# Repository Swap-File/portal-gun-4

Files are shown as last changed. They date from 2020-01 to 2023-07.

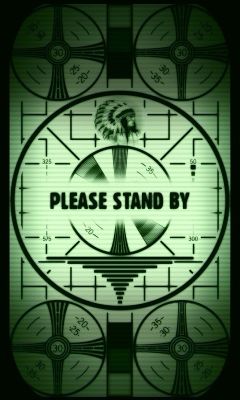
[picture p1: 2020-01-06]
internet/http/portalguns/test.jpg

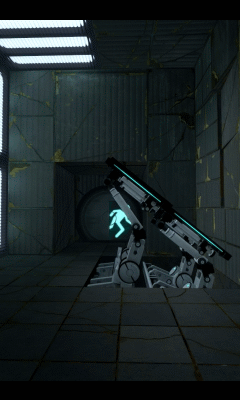
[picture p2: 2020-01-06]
intranet/assets/53.gif

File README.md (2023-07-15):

# portal-gun-4
Portal Gun IV

Gun:

[Raspberry Pi 4B](https://www.raspberrypi.org/) + [Laser Beam Pro C200](http://laserbeampro.com/) + [Pi NoIR Camera V2](https://www.raspberrypi.com/products/pi-noir-camera-v2/) + 3W IR Emitters

CAD Design inspired by [Kirby Downey](https://kirbydowney.com/)

5Ghz Bridge with hostapd via onboard WiFi + Fe-Pi Audio Z I2S Sound Card + USB CSR BT Dongle for tethering (avoids onboard WiFi/BT coexistence issues)

[Pololu MinIMU-9 v2](https://www.pololu.com/product/1268) + ADS1115 for Battery Meter and Temp Sensing

[4S 2200mAh LiPo](https://hobbyking.com/en_us/turnigy-2200mah-4s-20c-lipoly-pack-w-xt60-connector.html) + 3x [Pololu D36V28F5 5V 3.2A Regulators](https://www.pololu.com/product/3782) (Projector, CPU, Lighting and Sound)

APA102 LEDs + PAM8302 Class D Amplifier + ACS712 Current Sensor

KMS + EGL + GLES3 thanks to:

[kmscube](https://gitlab.freedesktop.org/mesa/kmscube/) + [OpenGL® ES 3.0 Programming Guide](https://github.com/danginsburg/opengles3-book) + [Modern OpenGL Tutorial Text Rendering 02](https://en.wikibooks.org/wiki/OpenGL_Programming/Modern_OpenGL_Tutorial_Text_Rendering_02)
 
Phone:

[QPython3](http://qpython.com/) + [Requests](http://docs.python-requests.org/en/latest/) + Bluetooth

Website:

[Apache](http://httpd.apache.org/) + [PHP](http://php.net/) + [mySQL](https://www.mysql.com/) on [Ubuntu](http://www.ubuntu.com/)

OS:
```
Raspberry Pi OS Lite
Release date: May 3rd 2023
System: 64-bit
Kernel version: 6.1
Debian version: 11 (bullseye)
Size: 308MB
Show SHA256 file integrity hash:
bf982e56b0374712d93e185780d121e3f5c3d5e33052a95f72f9aed468d58fa7
```
Packages:

```
gstreamer1.0-plugins-base gstreamer1.0-plugins-good gstreamer1.0-plugins-bad
libvisual-0.4-plugins gstreamer1.0-tools gstreamer1.0-plugins-ugly 
libgstreamer-plugins-base1.0-dev libgstreamer1.0-dev gstreamer1.0-alsa gstreamer1.0-libav
```
```
apache2 php libapache2-mod-php
```
```
dos2unix libdrm-dev libgles2-mesa-dev libgbm-dev ifstat python3-dbus libbluetooth-dev
hostapd libi2c-dev screen apt-file
```
Services:

```
systemctl unmask hostapd
systemctl enable hostapd
systemctl start hostapd
```
```
systemctl mask systemd-rfkill.socket systemd-rfkill.service
sudo apt purge libpam-chksshpwd
sudo apt remove libpam-chksshpwd
sudo apt purge rfkill
```
```
systemctl mask rpi-eeprom-update
systemctl disable apt-daily.service
systemctl disable apt-daily.timer
systemctl disable apt-daily-upgrade.timer
systemctl disable apt-daily-upgrade.service
sudo rpi-eeprom-update -a
```

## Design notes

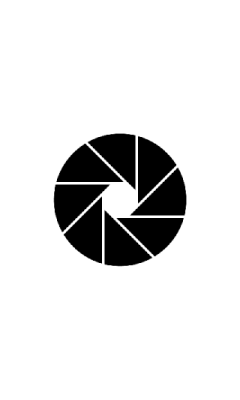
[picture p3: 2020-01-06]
intranet/assets/shutter.png

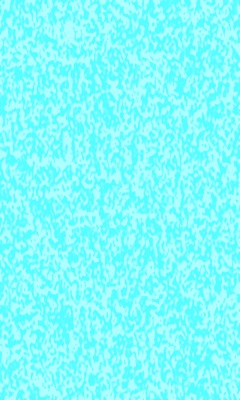
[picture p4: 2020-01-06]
intranet/assets/blue_0.jpg

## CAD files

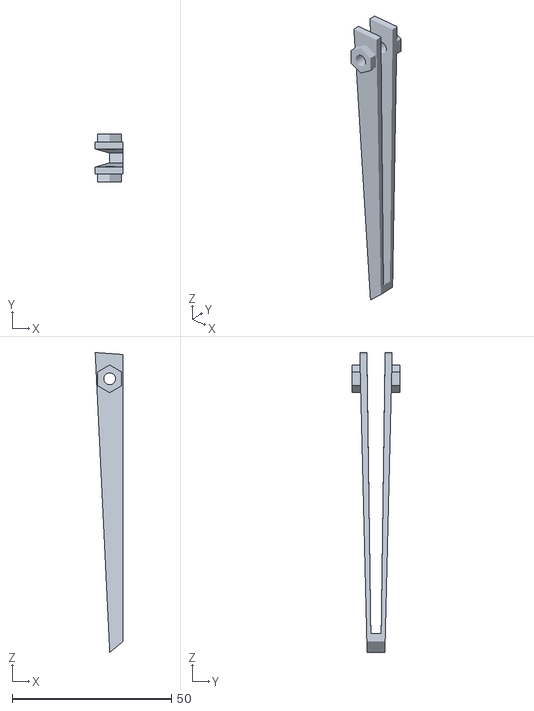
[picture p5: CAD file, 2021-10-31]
cad/finger/finger angle.stl
8.66 x 15.0 x 94.1

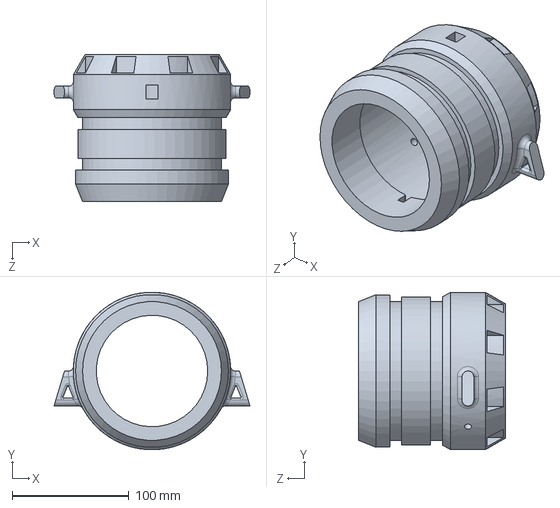
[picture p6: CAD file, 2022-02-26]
cad/front holes.SLDPRT
168.0 x 134.9 x 126.2 mm

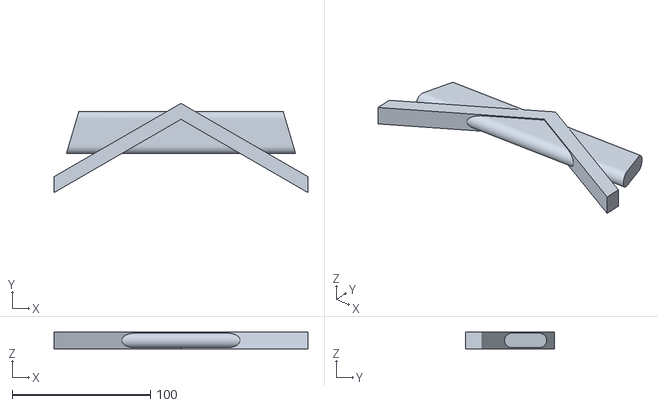
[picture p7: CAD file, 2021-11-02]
cad/trim/front trim holes only.stl
184.0 x 64.7 x 12.0

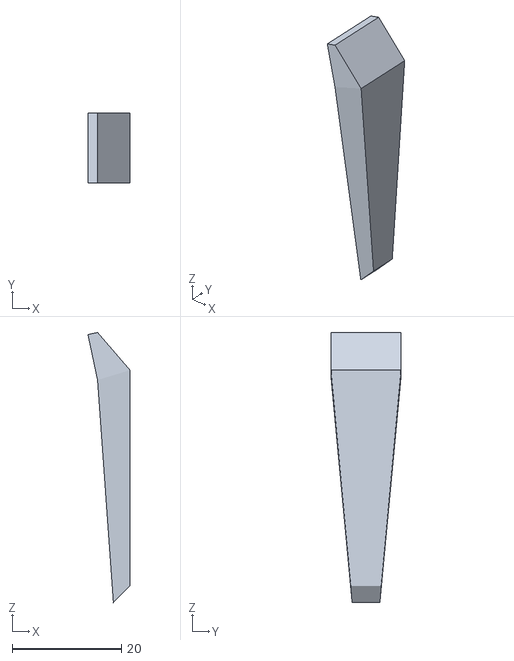
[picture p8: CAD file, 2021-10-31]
cad/finger/finger tip.stl
7.69 x 12.7 x 49.3

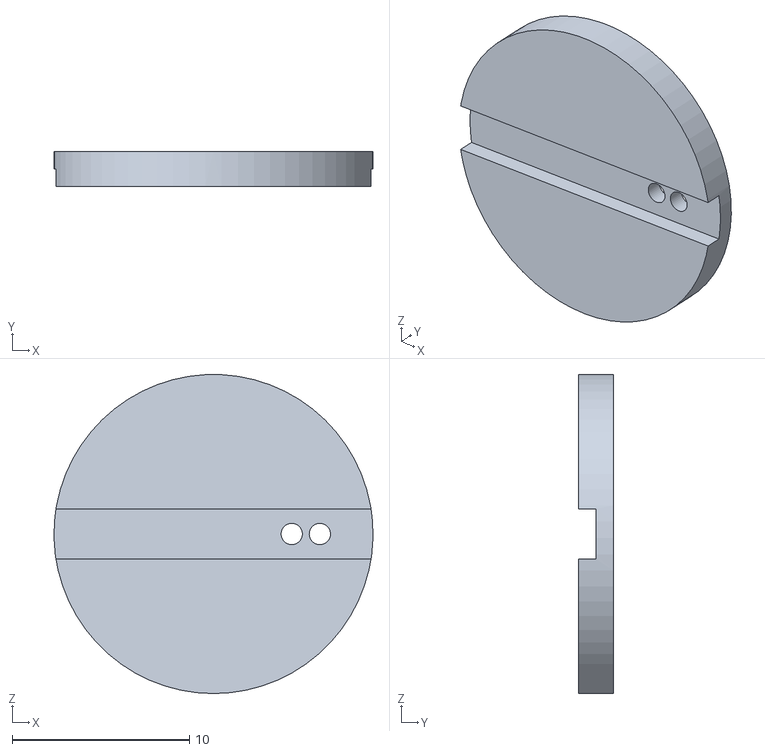
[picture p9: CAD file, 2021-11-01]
cad/projector shutter.STL
18.0 x 2.00 x 18.0

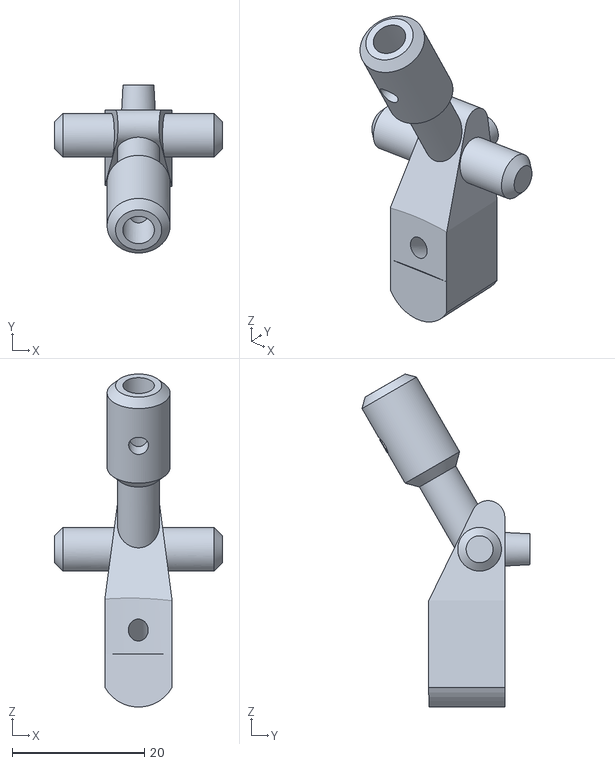
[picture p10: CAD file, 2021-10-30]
cad/finger/finger mount.STL
25.4 x 25.4 x 50.3

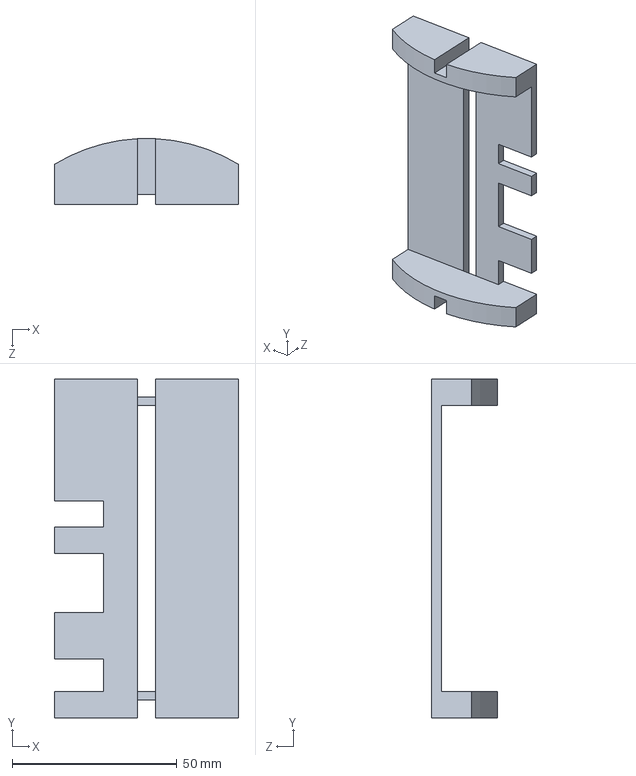
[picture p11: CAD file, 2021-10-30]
cad/sled lcd holder.SLDPRT
56.0 x 103.0 x 19.9 mm

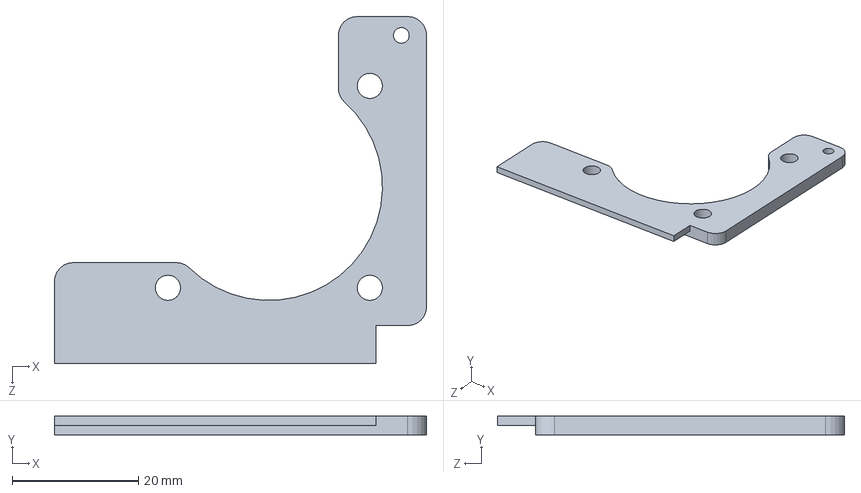
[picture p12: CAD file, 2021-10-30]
cad/fan bracket.SLDPRT
59.0 x 3.00 x 55.0 mm

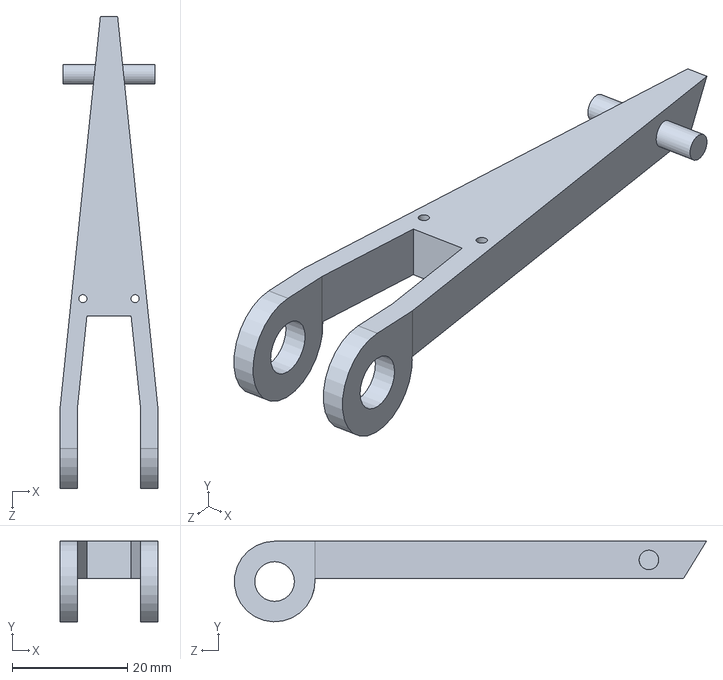
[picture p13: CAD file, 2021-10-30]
cad/finger/finger arm.SLDPRT
17.0 x 14.0 x 82.0 mm

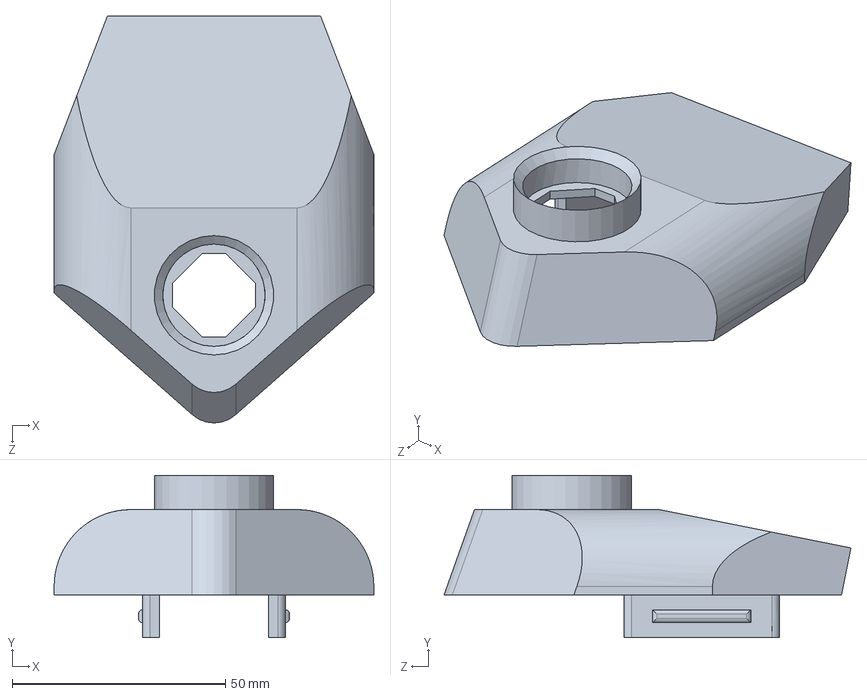
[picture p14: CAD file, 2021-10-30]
cad/Battery Lid.SLDPRT
75.0 x 38.0 x 95.5 mm

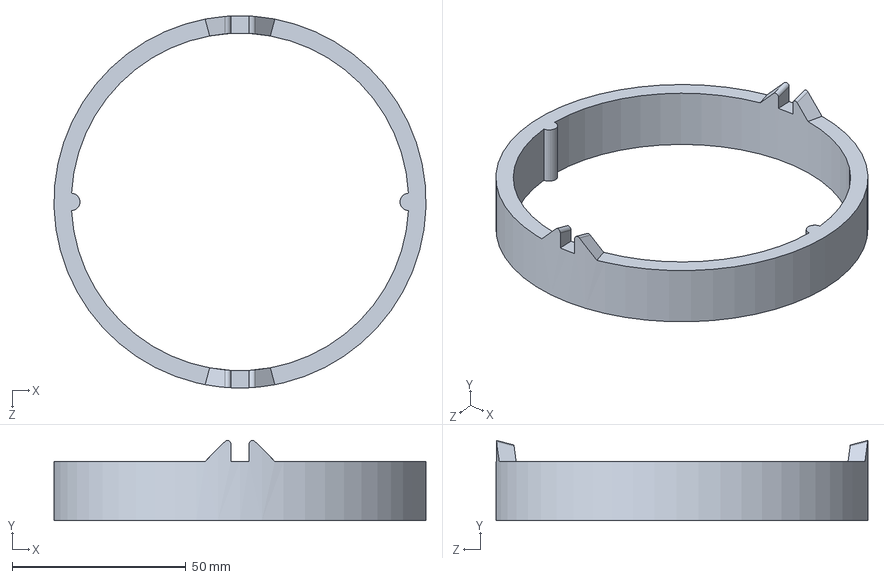
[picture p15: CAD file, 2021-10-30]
cad/led ring back.SLDPRT
107.0 x 23.0 x 106.9 mm

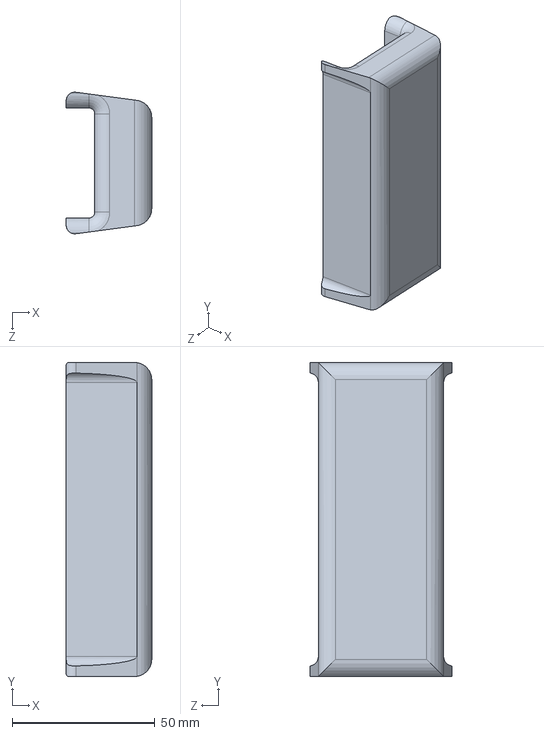
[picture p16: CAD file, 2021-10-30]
cad/big hand adapter.SLDPRT
30.0 x 110.0 x 49.6 mm

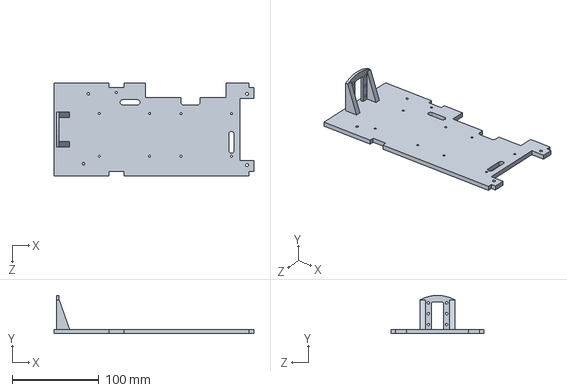
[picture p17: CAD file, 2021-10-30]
cad/sled.SLDPRT
230.0 x 44.1 x 107.5 mm

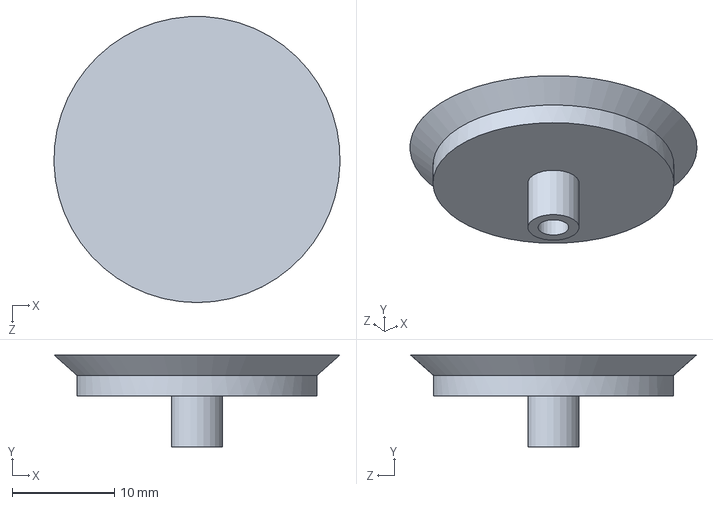
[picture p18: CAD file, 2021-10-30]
cad/led.SLDPRT
28.0 x 9.00 x 28.0 mm

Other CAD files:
cad/back.SLDPRT
cad/led ring front.SLDPRT
cad/finger gaurd.SLDPRT
cad/stand.SLDPRT
cad/3D.dwg
cad/Battery Lid.STL
cad/Sheets.dwg
cad/back.STL
cad/big hand adapter.STL
cad/fan bracket.STL
cad/finger gaurd.STL
cad/finger/finger arm.STL
cad/front holes.STL
cad/front.SLDPRT
cad/front.STL
cad/led ring back.STL
cad/led ring front.STL
cad/led.STL
cad/sled lcd holder.STL
cad/sled.STL
cad/stand.STL
cad/tool.SLDPRT
cad/tool.STL

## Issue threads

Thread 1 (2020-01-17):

projector power control

Swap-File, 2020-01-17:
delay start animations and sync with projector power

Swap-File, 2020-01-20:
update state diagram

Swap-File, 2020-03-15:
https://github.com/Swap-File/portal-gun-4/commit/aa162b3f9d81bb841b7df247740ffafaa37dea17

Closed 2020-03-15.

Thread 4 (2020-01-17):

fix points

Swap-File, 2020-01-17:
figure out why the points around the portal disappeared

Swap-File, 2020-01-20:
check this https://www.raspberrypi.org/forums/viewtopic.php?f=68&t=245646

Swap-File, 2020-02-06:
Switched to shaders

Closed 2020-02-06.

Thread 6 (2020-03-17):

fix intranet preview icons

Swap-File, 2020-03-17:

Swap-File, 2020-03-18:
Cleared out the live stuff that hasn't worked since V2.  Superseded by the dedicated physical aiming display on the device.
https://github.com/Swap-File/portal-gun-4/commit/fd465e689457e95f47c2515060cbd15374692820

Closed 2020-03-18.

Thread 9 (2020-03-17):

open shutter on state 0 when laser off?

Swap-File, 2020-03-17:

Swap-File, 2020-03-18:
https://github.com/Swap-File/portal-gun-4/commit/0edaa99c8b8bd9212dcef2553f66d64ddb35fb7e

may not use, its just fancy-ness

Swap-File, 2020-03-18:
Add this as an offshoot of shutter config, 0 is bypass, 1 is normal, 2 is fancy

Closed 2020-03-18.

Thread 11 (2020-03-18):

libvisual_corona

Swap-File, 2020-03-18:
look at the corona source code and figure out what its actually supposed to be doing with the input music

Swap-File, 2020-03-18:
void Corona::update(TimedLevel *pLevels)
{
	// Check for a beat
	int beatval = getBeatVal(pLevels);
	if (beatval > 1000)
	{
		int total = 0;
		for (int i = 0; i < 512; ++i)
			total += 2 * pLevels->frequency[0][i];
		double currval = 1.0 - exp(-total / 40000.0);
		m_oldval = (m_oldval + currval) / 2.0;

		double tx, ty;
		getAvgParticlePos(tx, ty);
		// If most of the particles are low down, use a launch
		if (ty < 0.2 && rand() % 4 != 0) {
			int p;
			double bv = m_oldval * 5.0;
			for (p = 0; p < nbParticules; ++p)
			{
				Particle *it = m_particles + p;
				if (it->y < 0.1) {
					double x = (it->x - tx) / bv;
					it->yvel += 0.01 * bv * exp(-1000.0 * x * x);
				}
			}
		}
		else
		{	// Otherwise use a swirl
			tx += random(-0.1, 0.1);
			ty += random(-0.1, 0.1);
			double bv = 0.009 * m_oldval;
			double bv2 = 0.0036 * m_oldval;
			if (rand() % 2 == 0) bv = -bv;
			m_movement.x = tx;
			m_movement.y = ty;
			m_movement.tightness = random(0.8 * bv, bv);
			m_movement.pull = random(1 - bv2, 1 - 0.2 * bv2);
			m_swirltime = 1;
		}

		pLevels->lastbeat = pLevels->timeStamp;
	}

	// Deal with the particles
	int p;
	for (p = 0; p < nbParticules; ++p)
	{
		Particle *it = m_particles + p;
		// Apply gravity
		it->yvel -= 0.0006;		// the gravity value

		// If there's an active swirl, swirl around it
		if (m_swirltime > 0) {
			double dx = it->x - m_movement.x;
			double dy = it->y - m_movement.y;
			double d = dx * dx + dy * dy;
			double ds = ::sqrt(d);
			double ang = atan2(dy, dx) + m_movement.tightness / (d + 0.01);
			it->xvel += (ds * m_movement.pull * cos(ang) - dx);
			it->yvel += (ds * m_movement.pull * sin(ang) - dy);
		}

		// Gitter
		it->xvel += random(-0.0002, 0.0002);
		it->yvel += random(-0.0002, 0.0002);

		// Clamp the velocity
		if (it->xvel < -0.1 ) it->xvel = -0.1;
		if (it->xvel > 0.1 ) it->xvel = 0.1;
		if (it->yvel < -0.1 ) it->yvel = -0.1;
		if (it->yvel > 0.1 ) it->yvel = 0.1;

		// Randomly move the particle once in a while
		if (rand() % (nbParticules / 5) == 0)
		{
			it->x = random(0, 1);
			it->y = random(0, 1);
			it->xvel = it->yvel = 0;
		}

		// Move and bounce the particle
		it->x += it->xvel;
		it->y += it->yvel;
		if (it->x < 0) { it->x = -it->x; it->xvel *= -0.25; it->yvel *= 0.25; }
		if (it->y < 0) { it->y = -it->y; it->xvel *= 0.25; it->yvel *= -0.25; }
		if (it->x > 1) { it->x = 2.0 - it->x; it->xvel *= -0.25; it->yvel *= 0.25; }
		if (it->y > 1) { it->y = 2.0 - it->y; it->xvel *= 0.25; it->yvel = 0; }
	}

	if (m_swirltime > 0) --m_swirltime;

	// Randomly change the delta field
	if (rand() % 200 == 0) chooseRandomSwirl();

	// Animate the waves
	m_waveloop += 0.6;

	// drawing.
	if (m_image != 0)
	{
		// Draw the particles on the bitmap
		drawParticules();

		// Apply the deltafield and update a few of its points
		applyDeltaField(m_nPreset == PRESET_BLAZE && m_width * m_height < 150000);

		int n = (m_width * m_height) / 100;
		for (int i = 0; i < n; ++i)
			setPointDelta(rand() % m_width, rand() % m_height);

		// If on the blaze preset, draw the particles again
		if (m_nPreset == PRESET_BLAZE)
			drawParticules();

		drawReflected();

		// Blur the bitmap
		blurImage();

		// If on the blaze preset, draw the particles one last time
		if (m_nPreset == PRESET_BLAZE)
			drawParticulesWithShift();
	}
}

Closed 2020-03-18.

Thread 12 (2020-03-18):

current meter

Swap-File, 2020-03-18:
do something useful with the current meter data that is being collected

Swap-File, 2020-04-21:
rearrange display.  add bt stats?

Swap-File, 2020-05-08:
https://github.com/Swap-File/portal-gun-4/commit/626576db60c85a3c7bc4a511efb7a6b8bfc2cf9d

Closed 2020-05-08.

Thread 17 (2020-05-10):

intranet control

Swap-File, 2020-05-10:
remove picture taking
remove camera streaming (mjpg removal)
combine camera and projector setting
review what 4 stats are shown in the corner

Closed 2020-05-10.

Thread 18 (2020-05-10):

default playlists

Swap-File, 2020-05-10:
set a good default solo and duo playlist
revisit standard saved playlists

Swap-File, 2020-05-19:
Solo playlist order will be different on Gordon and Chell to keep things exciting if both users are in solo mode within eyeshot.

Duo playlist will stay the same for consistency, and because generally in duo mode there is a lot of quick switching, then an effects demo on one gun.

Swap-File, 2020-05-20:
https://github.com/Swap-File/portal-gun-4/commit/4ff93dd91c9ad7c4bd30ed342ac6f2b7df053dd4

Closed 2020-05-20.

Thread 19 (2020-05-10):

calibrate party mode

Swap-File, 2020-05-10:
check volume levels for party modes

Swap-File, 2020-05-20:
Investigate if SGTL5000 DAP works, apply dap to incoming audio?
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

Swap-File, 2020-06-02:
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

This setting is not exposed in the driver.
https://github.com/torvalds/linux/blob/master/sound/soc/codecs/sgtl5000.c

So using the DAP for incoming audio will be non-trivial.  Test with fixed setting like before.

Swap-File, 2020-06-05:
Basic sgtl5000 driver to take over mux control:
https://github.com/Swap-File/portal-gun-4/commit/7dc68987c342c3e8444456e9736911a3bff56a97

breaks alsamixer, but meh, it works.

Swap-File, 2020-06-05:
Goal:
Likely using AVC, bass enhancement as LPF only, and potentially 5 band EQ.

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

Swap-File, 2020-06-07:
Check SYNAE, promote Goom.

Swap-File, 2020-06-08:
SYNAE init fixed, goom promoted, more calibration needed.

Swap-File, 2020-06-08:
Calibrate: Volume levels, potentially EQ balance the incoming signal

Swap-File, 2020-06-11:
https://github.com/Swap-File/portal-gun-4/commit/8dac6cc745b6f9d2c41d8cf5ebbc5b44331daddb

Closed 2020-06-11.

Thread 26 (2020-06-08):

check video assets

Swap-File, 2020-06-08:
some videos start with an audio glitch, check the source material, potentially reencode

Swap-File, 2020-06-09:
https://github.com/Swap-File/portal-gun-4/commit/a0cc7c408f124f0d3c21228ec15d06cfa1bde46a

Closed 2020-06-09.

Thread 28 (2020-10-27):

check spi

Swap-File, 2020-10-27:
spidev or bcm?

Swap-File, 2021-05-06:
bcm for now, needed for i2c anyway

Swap-File, 2021-08-07:
/dev/i2c and /dev/spi was tested, both should not be used, they are slow and the kernel prevents soundcard access.

Closed 2021-05-06.

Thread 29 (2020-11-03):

3d print enclosure?

Swap-File, 2020-11-03:

Swap-File, 2021-05-06:
Slated for version 4.1
3D Printed Case
Poly-carbonate Tube

Swap-File, 2022-01-27:
Keeping open until orange shoulder straps are sewn

Swap-File, 2022-02-26:
https://github.com/Swap-File/portal-gun-4/commit/b21b49ae80c27955f57669446c3839c97663f470

Closed 2022-03-03.

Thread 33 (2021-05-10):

state machine error

Swap-File, 2021-05-10:
On a swap from self to duo mode, we must spend one cycle in state 3 to allow the gstreamer engine time to switch while the portal is closed.

The state machine can now make two state transitions in one cycle hiding from gstreamer that we were ever inside of state 3

Swap-File, 2021-05-16:
https://github.com/Swap-File/portal-gun-4/commit/fec140e2ff6ac00d4982683c3446e936d2ff19d9

Closed 2021-05-16.

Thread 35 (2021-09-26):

paint over red leds

Swap-File, 2021-09-26:

Swap-File, 2021-10-01:
black sharpie

Closed 2021-10-01.

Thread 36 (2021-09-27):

handle led doesnt always animate

Swap-File, 2021-09-27:

Swap-File, 2021-10-01:
https://github.com/Swap-File/portal-gun-4/commit/49b9986c8119ec3a0ab07c4f6d1ba017873bc58d

Closed 2021-10-01.

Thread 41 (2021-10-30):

check imu data

Swap-File, 2021-10-30:

Swap-File, 2022-01-31:
https://github.com/Swap-File/portal-gun-4/commit/9bab527c6e233b79e642b619883a2afe74fdbfb5

Closed 2022-01-31.

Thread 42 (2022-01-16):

Update To bullseye

Swap-File, 2022-01-16:
Major camera changes

Check if KMS changes affect portal multi-monitor

measure new latency

Swap-File, 2022-01-16:
python-dbus is now dbus-python

Swap-File, 2022-01-17:
remove libgstaasink.so & libgstcacasink.so

Swap-File, 2022-01-21:
libcamera does not allow direct i2c access while the camera is in use, this breaks all the i2c functionality in all accessories, and affects timing.

libcamerasrc has minimal output support and is not ready for use.

libcamera-vid is acceptable, and UDP streaming works, but again it prevents direct i2c use.

Will self compile rpicamsrc and raspivid and check.

Good news is, I learned direct UDP streaming from any source (raspivid or libcamera-vid) likely the way to go for now.  It's faster than gstreamer's libcamsrc or rpicamsrc.

I can reflect the UDP packets for camera preview with the follow IP tables rule, lowering the primary video stream latency.
Example:
iptables -t mangle -A POSTROUTING -p udp --dport 9000 -j TEE --gateway 127.0.0.1

Swap-File, 2022-01-21:
https://forums.raspberrypi.com/viewtopic.php?t=323390

" Edit /boot/config.txt, remove the line "camera_auto_detect=1", and add "start_x=1" and "gpu_mem=128". Rebooting at this stage will reload the old V4L2 driver. Stop at this point if that is sufficient for your needs.

If you need raspistill/vid, then build the userland libraries for yourself.
Code: Select all

cd ~
sudo apt install cmake
mkdir bin
git clone https://github.com/raspberrypi/userland
cd userland
./buildme
cp build/bin/* ~/bin/
"

Swap-File, 2022-01-21:
Note: using Raspivid's preview window, it looks like a lower bound for video latency is ~115ms (camera to monitor)

Swap-File, 2022-01-21:
gst-launch-1.0 rpicamsrc ! image/mjpeg, width=640, height=480, framerate=30/1 ! queue ! udpsink port=9001 sync=false host=127.0.0.1
gst-launch-1.0 udpsrc port=9001 ! jpegdec ! queue ! kmssink sync=false
5% CPU  ~115ms

Swap-File, 2022-01-22:
64 bit OS benchmarks:

libcamera-vid -t 0 -o udp://127.0.0.1:9001 --width 640 --height 480 --codec MJPEG --framerate 30 --nopreview
gst-launch-1.0 udpsrc port=9001 ! jpegdec ! queue ! kmssink sync=false
50% CPU ~300ms of latency!

gst-launch-1.0 libcamerasrc ! video/x-raw, width=640, height=480, framerate=30/1 ! videoconvert ! jpegenc ! udpsink port=9001 sync=false host=127.0.0.1
gst-launch-1.0 udpsrc port=9001 ! jpegdec ! queue ! kmssink sync=false
45% CPU ~115ms

rpicamsrc does not work due to mmal support being incomplete on 64 bit Pi OS

Conclusion:  Bullseye + rpicamsrc

Will likely stay with BCM i2c for now, but I should investigate the latency cost to switch to linux native i2c.

Swap-File, 2022-01-22:
rtpvrawpay has slightly higher latency than jpegenc, and double the CPU, I guess packet handling overhead?

Swap-File, 2022-01-22:
gst-launch-1.0 rpicamsrc keyframe-interval=10 preview=0 ! video/x-h264,width=400,height=240,framerate=30/1,profile=baseline ! queue !  rtph264pay config-interval=1 pt=96 ! udpsink host=127.0.0.1 port=9000
gst-launch-1.0 udpsrc port=9000 caps=application/x-rtp,media=video,clock-rate=90000,encoding-name=H264 ! rtph264depay ! avdec_h264 ! queue ! kmssink sync=false
8% CPU 160ms latency

libcamera-vid -t 0 -o udp://127.0.0.1:9001 --width 640 --height 480 --codec h264--framerate 30 --nopreview
horrible latency, didn't even measure

raw video from rpicamsrc or libcamerasrc is the way to go.  will need to check if anything is better than jpegenc

Swap-File, 2022-01-22:
gst-launch-1.0 -vvv  rpicamsrc ! video/x-raw, width=640, height=480, framerate=30/1 ! kmssink sync=false
Lower limit of ~115ms

Swap-File, 2022-01-22:
fake kms is required for fixed resolution to work perfectly, no problems detect

Swap-File, 2022-01-26:
kms is a no go until hot plug is fixed.  power cycling projector while program is running can lead to a crash, is inconsistent.

Swap-File, 2022-02-01:
Invalid page flip at "drmDropMaster(drm.fd);" ? may need to move drmDropMaster(drm.fd); to the end of the function.

Or could be that drm_wait_master isn't waiting long enough at init, will test.

I've never seen the failure while running, only at init.

Swap-File, 2022-02-01:
I don't think I've triggered this since bullseye, it used to occasionally happen on cold boot.

`   drm = init_drm_legacy(device, mode_str, vrefresh,0);
    if (!drm ) {
        printf("failed to initialize DRM\n");
        system("sudo reboot");
        return -1;
    }`

Swap-File, 2022-02-02:
re-evaluate kms vs fkms on bullseye with drm double init fix

Closed 2023-07-16.

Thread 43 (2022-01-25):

fix playlist load

Swap-File, 2022-01-25:
fix playlist load when playlist is shorter than current.

Swap-File, 2022-01-27:
https://github.com/Swap-File/portal-gun-4/commit/51320e9fa7faed62cd76063ea01360fc0269d376

good enough, playlist management could be broken out into it's own file at some point

Closed 2022-01-27.

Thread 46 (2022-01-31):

Test website streaming

Swap-File, 2022-01-31:

Swap-File, 2022-02-08:
works

Swap-File, 2022-02-09:
Test gun power cycle while script is running (auto recovery behavior)

Swap-File, 2022-02-10:
works

Closed 2022-02-10.

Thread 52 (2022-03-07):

Solo Mode State Machine?

Swap-File, 2022-03-07:
Right now, solo mode takes a lot of presses to use.

Do we want to reduce the button presses?

3-1-1-1 could turn into 3-1-1 or 3-1

Swap-File, 2022-09-26:
nah, keeping it consistent for now

Closed 2022-09-26.

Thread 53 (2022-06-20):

intermittent first camera init fail

Swap-File, 2022-06-20:
Check if camera failure happens if Gordon projects and cell quick switches before Chell ever uses projector.

Swap-File, 2022-09-26:
https://github.com/Swap-File/portal-gun-4/issues/55 Maybe?

Closed 2022-09-26.

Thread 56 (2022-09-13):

rewind displays frames of video

Swap-File, 2022-09-13:

Closed 2022-09-26.

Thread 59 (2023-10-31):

pwm support on pi5?

Swap-File, 2023-10-31:
"6by9:

General advice would be to use the Linux standard APIs as they are then portable between all platforms. That would be libgpio for GPIO, and [sysfs](https://www.kernel.org/doc/html/latest/driver-api/pwm.html#using-pwms-with-the-sysfs-interface) for PWM (I'm amazed they haven't updated that one as sysfs is a pain)."

"Adafruit:

So clearly libgpiod is the winner at just over 3 times the speed of gpiozero!"

Swap-File, 2023-10-31:
https://github.com/raspberrypi/linux/blob/8dcc16f0adc50f5cb8a11a6dde238131d0ca45a0/drivers/pinctrl/pinctrl-rp1.c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

Swap-File, 2023-11-15:
https://forums.raspberrypi.com/viewtopic.php?t=359251

The SoC's onboard PWM block is probed first and has 2 channels - it gets called pwmchip0, and its created PWMs are called pwm0 and pwm1. The RP1 PWM controller has 4 channels, and when it probes there are already 2 PWMs in the system so it gets called pwmchip2 and creates global PWMs pwm2, pwm3, pwm4 and pwm5. But, the sysfs interface uses per-controller indexes to label its pwms, so exporting channel 2 of pwmchip2 creates .../pwmchip2/pwm2 (not pwm4).

(Maybe 2 external PWMs are still available? would still likely be on the wrong pins)

The GPIO sysfs interface and PWM sysfs interface are two different subsystems. The GPIO one is deprecated whilst the PWM one isn't.

```
#!/bin/bash
CHANNEL=2
CHIP=pwmchip2
PWM=pwm$CHANNEL

echo $CHANNEL > /sys/class/pwm/$CHIP/export
sleep 1
echo 240000 > /sys/class/pwm/$CHIP/$PWM/period
echo 120000 > /sys/class/pwm/$CHIP/$PWM/duty_cycle
echo 1 > /sys/class/pwm/$CHIP/$PWM/enable
```

Swap-File, 2024-03-05:
Wait for WiringPi to support Pi5 PWM prior to future testing.

https://github.com/WiringPi/WiringPi
https://github.com/GrazerComputerClub/WiringPi/issues/21

Swap-File, 2024-03-05:
Wait until WiringPi supports PWM for future investigation:

https://github.com/WiringPi/WiringPi

Swap-File, 2024-12-06:
Looks like WiringPi supports HW PWM on the Pi5.

https://github.com/WiringPi/WiringPi/pull/270

Test it on the Portal Guns.

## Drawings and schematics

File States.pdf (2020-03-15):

## Solo Mode State Transitions

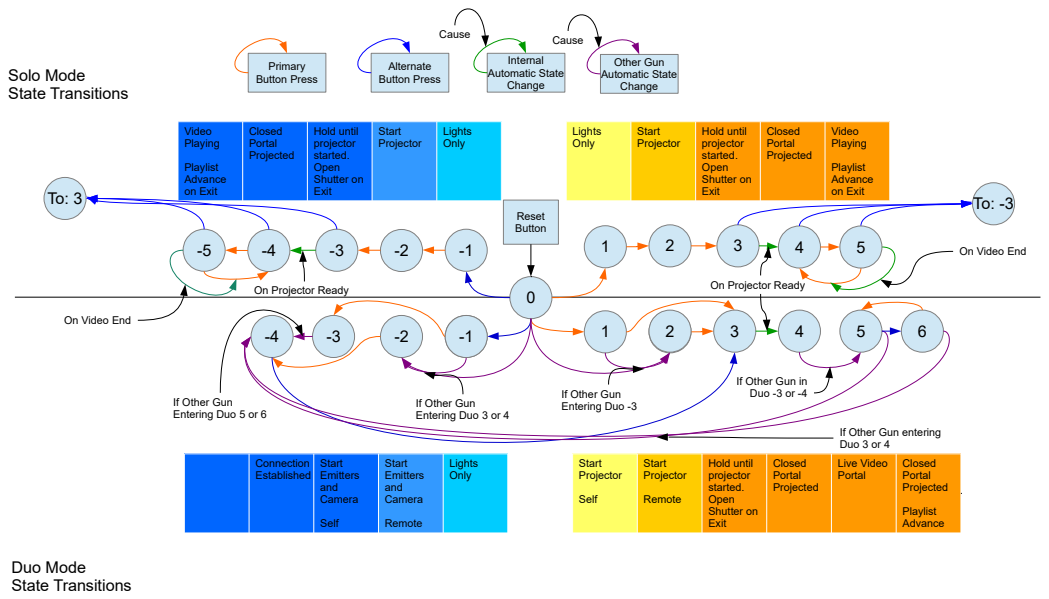
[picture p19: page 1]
Video Playing; Playlist Advance on Exit; Closed Portal Projected; Hold until projector started. Open Shutter on Exit; Start Projector; Lights Only; Connection Established; Start Emitters and Camera; Self; Remote; Playlist Advance; Primary Button Press; Alternate Button Press; Reset Button; Internal Automatic State Change; Cause; Duo Mode State Transitions; Other Gun Automatic State Change

On Video End

On Projector Ready

If Other Gun in
Duo -3 or -4

If Other Gun
Entering Duo -3

Entering Duo 5 or 6

Entering Duo 3 or 4

If Other Gun entering
Duo 3 or 4
Live Video
Portal

## Solo Mode Duo Force

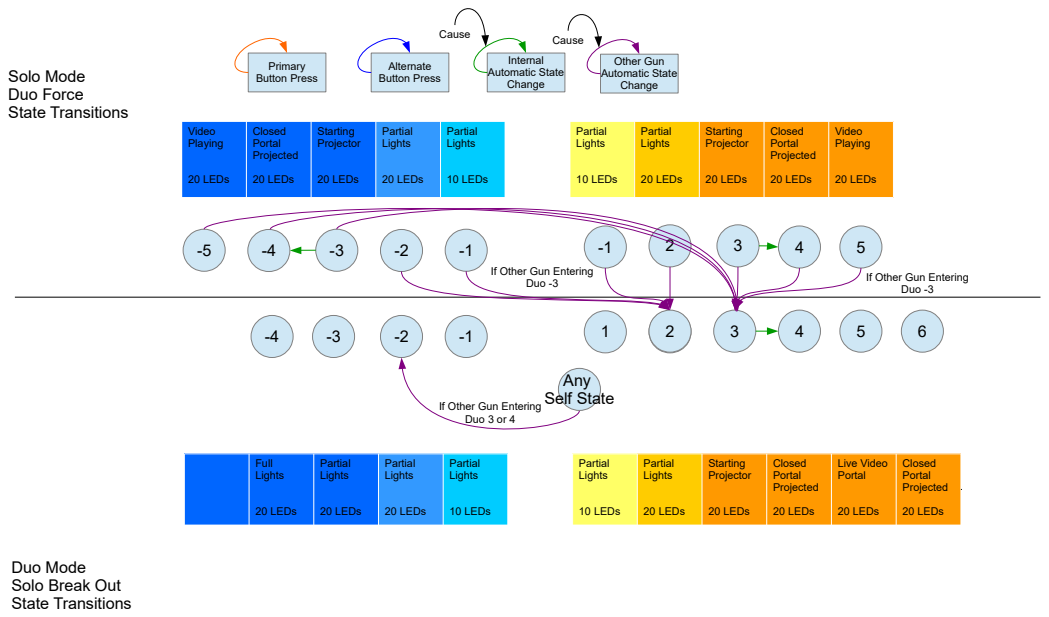
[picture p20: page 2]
Video Playing; 20 LEDs; Closed Portal Projected; Starting Projector; Partial Lights; 10 LEDs; Full Lights; Live Video Portal; State Transitions; Any; Duo 3 or 4; Duo -3; If Other Gun Entering; Primary Button Press; Alternate Button Press; Internal Automatic State Change; Cause; Other Gun Automatic State Change

If Other Gun Entering

Self State If Other Gun Entering

Duo Mode
Solo Break Out
State Transitions

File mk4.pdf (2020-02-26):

# Cellphone Bridge

# Website

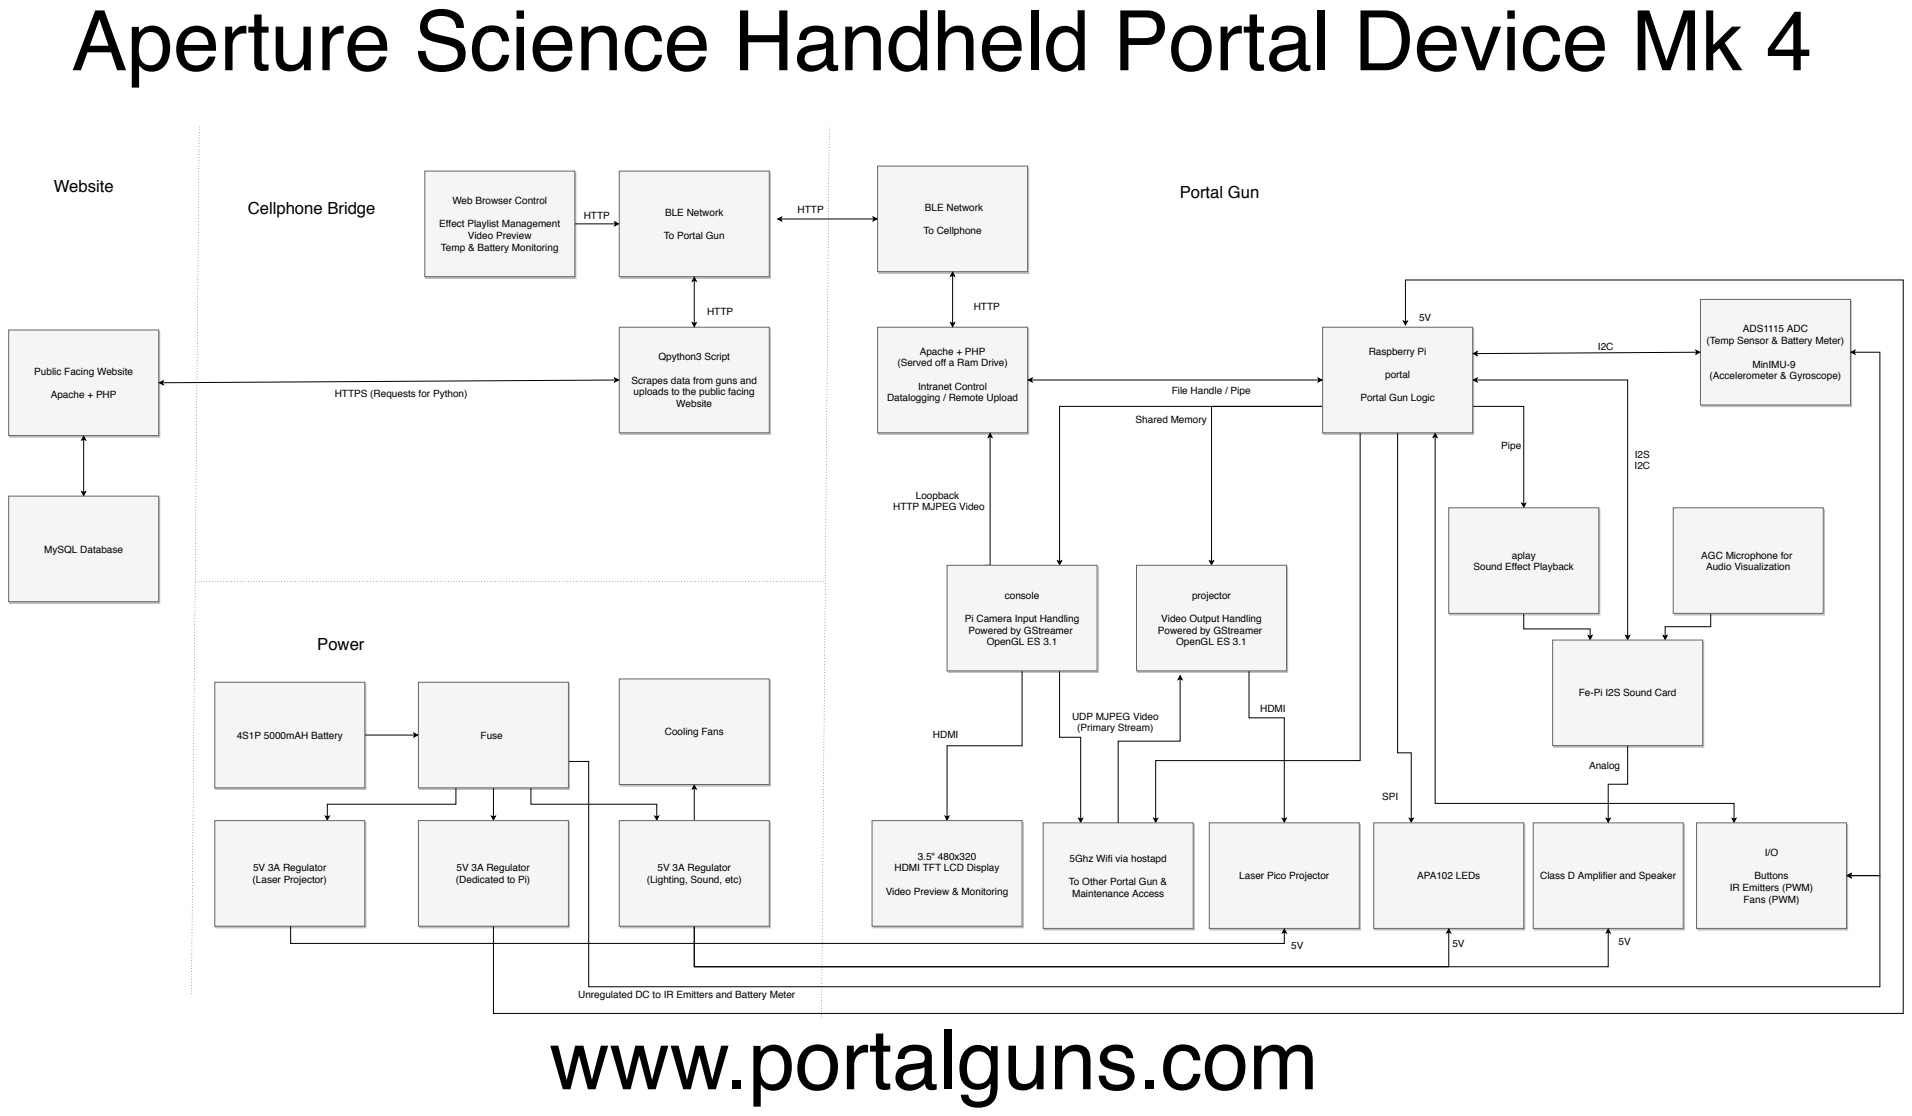
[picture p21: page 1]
BLE Network; Qpython3 Script; Website; Apache + PHP; HTTP; To Cellphone; Intranet Control; Pipe; Shared Memory; SPI; Raspberry Pi; portal; ADS1115 ADC; MinIMU-9 (Accelerometer & Gyroscope); aplay; HDMI; projector; Laser Pico Projector; APA102 LEDs; Class D Amplifier and Speaker; Portal Gun; 4S1P 5000mAH Battery; Fuse; Cooling Fans; Power; MySQL Database; 5V 3A Regulator (Laser Projector); console; Analog

Aperture Science Handheld Portal Device Mk 4

Web Browser Control

Effect Playlist Management
Video Preview
Temp & Battery Monitoring

To Portal Gun

(Temp Sensor & Battery Meter)

Apache + PHP
(Served off a Ram Drive)

Public Facing Website

Scrapes data from guns and
uploads to the public facing

HTTPS (Requests for Python)

Datalogging / Remote Upload

File Handle / Pipe

Portal Gun Logic

Loopback
HTTP MJPEG Video

AGC Microphone for
Audio Visualization

Sound Effect Playback

Pi Camera Input Handling
Powered by GStreamer
OpenGL ES 3.1

Video Output Handling

Fe-Pi I2S Sound Card

UDP MJPEG Video
(Primary Stream)

HDMI TFT LCD Display

5Ghz Wifi via hostapd

5V 3A Regulator
(Dedicated to Pi)

(Lighting, Sound, etc)
www.portalguns.com

Buttons
IR Emitters (PWM)
Fans (PWM)

To Other Portal Gun &
Maintenance Access

Video Preview & Monitoring

Unregulated DC to IR Emitters and Battery Meter

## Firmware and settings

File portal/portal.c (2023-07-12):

#include "common/memory.h"
#include "i2c.h"
#include "io.h"
#include "led.h"
#include "udp.h"
#include "pipe.h"
#include "state.h"
#include <stdio.h>
#include <stdlib.h> //exit
#include <signal.h> //SIGPIPE
#include <unistd.h> //getuid
#include <bcm2835.h>

void INThandler(int dummy) {
    printf("\nCleaning up...\n");
	pipe_cleanup();
	printf("LED wipe...\n");
    led_wipe();
    shared_cleanup();
    exit(1);
}

int main(void)
{
    if (getuid()) {
        printf("Run as root!\n");
        exit(1);
    }

    /* cleanup incase of straggling processes */
    pipe_cleanup();

    struct gun_struct *this_gun;
    shared_init(&this_gun,true);

    /* catch ctrl+c for exit */
    signal(SIGINT, INThandler);
    signal(SIGTERM, INThandler);
    signal(SIGKILL, INThandler);

    /* setup libraries */
	udp_init(this_gun->gordon);
	pipe_init(this_gun);
    bcm2835_init();
    led_init(this_gun->gordon);
    io_init();
    i2c_init();
 
    /* toggles every other cycle, cuts 100hz core tick speed to 50hz */
    bool freq_50hz = true;

    /* reset timer to now to avoid missing first cycle */
    uint32_t time_start = millis();

    while (1) {
        bool frameskip = false;
        /* Cycle Delay */
        time_start += 10;
        uint32_t predicted_delay = time_start - millis();
        if (predicted_delay > 10) predicted_delay = 0; //check for overflow
        if (predicted_delay != 0) {
            /* Update servos at 20ms intervals assuming we have enough delay, otherwise skip it */
            if (predicted_delay >= 2 && freq_50hz) {
                predicted_delay -= io_servo(this_gun->servo_open);
            }
            delay(predicted_delay);
        } else {
            time_start = millis(); //reset timer to now to skip idle
            frameskip = true;
        }

        /* Cycle Setup */
        this_gun->clock = millis(); //stop time for duration of frame
        freq_50hz = !freq_50hz;

        this_gun->state_duo_previous = this_gun->state_duo;
        this_gun->state_solo_previous = this_gun->state_solo;
        this_gun->other_gun_state_previous = this_gun->other_gun_state;

        /* Program Code */
        pipe_update(this_gun);

        /* Read Physical Buttons */
        int button_event = io_update(this_gun);
        if (button_event == BUTTON_LONG_RESET) system("reboot");
		
		/* Handle remote buttons  */
		pipe_button_out(button_event,this_gun->gordon);

        /* Otherwise Read Web Buttons */
        if (button_event == BUTTON_NONE) button_event = pipe_www_in(this_gun);
        //read other gun's data, only if no button events are happening this cycle

        /* Otherwise Read Other Gun */
        while (button_event == BUTTON_NONE) {
            int result = udp_receive_state(&(this_gun->other_gun_state),&(this_gun->other_gun_clock),&(this_gun->other_gun_health));
            if (result <= 0) break;  //read until buffer empty
            else this_gun->other_gun_last_seen = this_gun->clock;  //update time data was seen
            if (millis() - this_gun->clock > 5) break; //flood protect
        }

        /* Process State changes */
        state_engine(button_event,this_gun);

        /* Alternate blocking tasks to keep core at 100hz */
        if(freq_50hz)
            this_gun->brightness = led_update(this_gun);
        else
            i2c_update(this_gun);

        /* Send data to other gun and www output */
        static uint32_t time_udp_send = 0;
        if (this_gun->clock - time_udp_send > 100) {
            udp_send_state(this_gun->state_duo,this_gun->clock,this_gun->gun_health);
            time_udp_send = this_gun->clock;
            pipe_www_out(this_gun);
        }

        /* FPS counter */
        fps_counter("Portal:    ",this_gun->clock * 1000,frameskip);
    }
    return 0;
}

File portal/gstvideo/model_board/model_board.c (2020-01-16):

#include <stdio.h>
#include <stdlib.h>
#include <math.h>  //sqrt
#include <stdbool.h>
#include <gst/gst.h>
#include <gst/gl/gl.h>
#include <GL/glx.h>
#include <GL/glxext.h>
#include "png_texture.h"
#include "../gstvideo.h"

int last_acceleration[2] = {0,0};

//textures
GLuint orange_1,blue_n,orange_n,orange_0,blue_0,blue_1,texture_orange,texture_blue,circle64;

//vertex lists
GLuint video_quad_vertex_list,event_horizon_vertex_list,event_horizon2_vertex_list,portal_vertex_list,shutter_vertex_list;

float portal_spin = 0;
float event_horizon_spin = 0;

float event_horizon_vertex_list_shimmer = 0;
bool event_horizon_vertex_list_shimmer_direction = true;

float event_horizon_transparency_level = 0;

float global_zoom = 0;

float torus_offset[360];
float running_magnitude;
float angle_target;
float angle_target_delayed;

//texture scrolling
GLfloat donut_texture_scrolling = 0.0;

/* Borrowed from glut, adapted */
void draw_torus_vbo(){

	#define r 1.4
	#define R 9.8
	#define nsides 30
	#define rings 60
	
	int texcount=0,vertcount=0;
	
	GLfloat points[(nsides + 1) * rings * 2 *6];
	GLfloat tex[(nsides + 1) * rings * 2 * 4];

	GLfloat ringDelta = 2.0 * M_PI / rings;  //x and y 
	GLfloat sideDelta = 2.0 * M_PI / nsides; //z

	GLfloat theta = 0.0;
	GLfloat cosTheta = 1.0;
	GLfloat sinTheta = 0.0;
	
	for (int i = rings - 1; i >= 0; i--) {
		GLfloat theta1 = theta + ringDelta; //from 0 to 6.28
		
		GLfloat cosTheta1 = cos(theta1);
		GLfloat sinTheta1 = sin(theta1);

		GLfloat phi = 0.0;
		
		int index_deg = (360 - portal_spin + ( theta1 * 360  / (2*M_PI)));
		
		while (index_deg >= 360) index_deg -=360;
		
		GLfloat r_using = r + torus_offset[index_deg];
		GLfloat R_using = R - torus_offset[index_deg];
		
		for (int j = nsides; j >= 0; j--) {

			phi += sideDelta;
			
			GLfloat cosPhi = cos(phi);
			GLfloat sinPhi = sin(phi);
			
			GLfloat dist = R_using + r_using * cosPhi;
			
			GLfloat s0 = 20.0 * theta / (2.0 * M_PI);
			GLfloat s1 = 20.0 * theta1 / (2.0 * M_PI);
			GLfloat t = 2.0 * phi / (2.0 * M_PI);  //this seems to control texture wrap around the nut

			//glNormal3f(cosTheta1 * cosPhi, -sinTheta1 * cosPhi, sinPhi);
			tex[texcount++] = s0;
			tex[texcount++] = t - donut_texture_scrolling;
			points[vertcount++] =cosTheta1 * dist;
			points[vertcount++] =-sinTheta1 * dist;
			points[vertcount++] =r_using * sinPhi;
		
			//glNormal3f(cosTheta * cosPhi, -sinTheta * cosPhi, sinPhi);
			tex[texcount++] = s1;
			tex[texcount++] = t - donut_texture_scrolling;
			points[vertcount++] =cosTheta * dist;
			points[vertcount++] =-sinTheta * dist;
			points[vertcount++] =r_using * sinPhi;
		}
		
		theta = theta1;
		cosTheta = cosTheta1;
		sinTheta = sinTheta1;
	}
	
	glTexCoordPointer(2, GL_FLOAT, 0, tex);
	glVertexPointer(3, GL_FLOAT, 0, points);
	glDrawArrays(GL_TRIANGLE_STRIP, 0, (nsides + 1) * rings * 2);	//3720 vectors
}

//trail of points
#define TRAIL_QTY    6
#define TRAIL_LENGTH 20
#define TRAIL_OD     9.2
#define TRAIL_ID     2
static float cardinal_offset = 0.0;
static float helical_offset = 0.0;
static GLfloat point_vertexes[TRAIL_QTY * 3 * TRAIL_LENGTH];
static GLfloat point_colors[TRAIL_QTY * 4 * TRAIL_LENGTH];
static int head_offset = 0;

void draw_point_sprite_vertexes(void){
	
	//first decay ALL trail points, alpha is stored in 4th positions of color array
	for (int i = 3; i < TRAIL_QTY * 4 * TRAIL_LENGTH; i += 4) point_colors[i] *= 0.9;
	
	//overwrite the oldest point in each tail with the new head, render order doesnt matter
	head_offset = (head_offset + 1) % TRAIL_LENGTH; 
	float helical_index = 0;
	//do each head once
	for (int trail_head = 0; trail_head < TRAIL_QTY; trail_head++){
		
		//find the start of each trail, add the offset to get to the new head
		int vertex_index = trail_head * 3 * TRAIL_LENGTH + head_offset * 3;
		int color_index  = trail_head * 4 * TRAIL_LENGTH + head_offset * 4;	
		
		//find how far around the circle this head is
		float cardinal_index = (float)trail_head * (( 2 * M_PI )/((float)3));  //evenly space all heads
		
		//offset the position to get movement in a circle (controls cardinal speed)
		float cardinal_position = cardinal_index + cardinal_offset; 
			
		//how far to spin the helix
		helical_index =	helical_index + (( 2 * M_PI )*60.0/360.0);
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

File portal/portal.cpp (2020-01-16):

#include "portal.h"
#include "sharedmem.h"
#include "i2cread.h"
#include "ledcontrol.h"
#include "udpcontrol.h"
#include "pipecontrol.h"
#include "statemachine.h"
#include <stdio.h>
#include <stdint.h>
#include <stdlib.h>
#include <string.h>
#include <signal.h>
#include <unistd.h>
#include <sys/types.h>
#include <time.h>
#include <bcm2835.h>

void INThandler(int dummy) {
	printf("\nCleaning up...\n");
	ledcontrol_wipe();
	pipecontrol_cleanup();
	exit(1);
}

int main(void){
	
	if (getuid()) {
		printf("Run as root!\n");
		exit(1);
	}

	pipecontrol_cleanup();
	
	struct this_gun_struct *this_gun;
	shm_setup(&this_gun,true );
	
	//catch broken pipes to respawn threads if they crash
	signal(SIGPIPE, SIG_IGN);
	//catch ctrl+c when exiting
	signal(SIGINT, INThandler);
	
	//stats
	uint32_t time_start = 0;
	int missed = 0;
	uint32_t time_fps = 0;
	int fps = 0;
	uint32_t time_delay = 0;
	int changes = 0;
	
	//setup libaries
	web_output(*this_gun);
	bcm2835_init();
	ledcontrol_setup();
	i2creader_setup();	
	udpcontrol_setup();
	pipecontrol_setup();
	
	bool freq_50hz = true; //toggles every other cycle, cuts 100hz to 50hz

	while(1){
		//cycle start code - delay code
		time_start += 10;
		uint32_t predicted_delay = time_start - millis(); //calc predicted delay
		if (predicted_delay > 10) predicted_delay = 0; //check for overflow
		if (predicted_delay != 0){
			delay(predicted_delay); 
			time_delay += predicted_delay;
		}else{
			time_start = millis(); //reset timer to now
			printf("MAIN Skipping Idle...\n");
			missed++;
		}
		this_gun->clock = millis();  //stop time for duration of frame
		freq_50hz = !freq_50hz; 
		this_gun->state_duo_previous = this_gun->state_duo;
		this_gun->state_solo_previous = this_gun->state_solo;
		this_gun->other_gun_state_previous = this_gun->other_gun_state;
		
		//program code starts here
		update_temp(&(this_gun->coretemp));
		update_ping(&(this_gun->latency));
		update_ifstat(&(this_gun->kbytes_wlan),IFSTAT_WLAN);
		update_ifstat(&(this_gun->kbytes_bnep),IFSTAT_BNEP);
		update_iw(&(this_gun->dbm), &(this_gun->tx_bitrate));
		
		//read states from buttons
		int button_event = BUTTON_NONE;	
		button_event = io_update(*this_gun);

		//if no event, read from the web
		if (button_event == BUTTON_NONE) button_event = read_web_pipe(*this_gun);
		//read other gun's data, only if no button events are happening this cycle

		//if still no event, read button from the other gun for processing
		while (button_event == BUTTON_NONE){
			int result = udp_receive_state(&(this_gun->other_gun_state),&(this_gun->other_gun_clock));
			if (result <= 0) break;  //read until buffer empty
			else this_gun->other_gun_last_seen = this_gun->clock;  //update time data was seen
			if (millis() - this_gun->clock > 5) break; //flood protect
		}

		if (this_gun->video_done){
			if (this_gun->state_solo == 4) this_gun->state_solo = 3;
			else if (this_gun->state_solo == -4) this_gun->state_solo = -3;
			this_gun->video_done = false;
		}
						
		//process state changes
		local_state_engine(button_event,*this_gun);
		if (button_event != BUTTON_NONE) changes++;
		
		//OUTPUT TO gstvideo (combo video and 3d data)
		//gstvideo_command(*this_gun, other_gun.clock);

		//switch off updating the leds or i2c every other cycle, each takes about 1ms
		if(freq_50hz){ 
			this_gun->brightness = led_update(*this_gun);
		}
		else{
			i2creader_update(*this_gun);
		}
		
		audio_effects(*this_gun);
	
		//send data to other gun
		static uint32_t time_udp_send = 0;
		if (this_gun->clock - time_udp_send > 100){
			udp_send_state(this_gun->state_duo,this_gun->clock);
			time_udp_send = this_gun->clock;
			web_output(*this_gun);
		}
		
		//cycle end code - fps counter and stats
		fps++;
		if (time_fps < millis()){		
			printf("MAIN FPS:%d mis:%d idle:%d%% changes:%d \n",fps,missed,time_delay/10,changes);
			fps = 0;
			time_delay = 0;
			time_fps += 1000;
			//readjust counter if we missed a cycle
			if (time_fps < millis()) time_fps = millis() + 1000;
		}	
	}
	return 0;
}

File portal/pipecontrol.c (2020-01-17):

#include "pipecontrol.h"
#include "portal.h"
#include <sys/resource.h> //setpriority
#include <unistd.h> //sleep
#include <fcntl.h>  
#include <stdio.h>
#include <stdlib.h> //system exit getenv
#include <string.h> //strstr
#include <sys/stat.h> //mkfifo  
#include <bcm2835.h>

int temp_in;
int web_in;

FILE *iw_fp;
FILE *ifstat_wlan0_fp;
FILE *ifstat_bnep0_fp;
FILE *bash_fp;
FILE *ping_fp;

void pipecontrol_cleanup(void){
	printf("KILLING OLD PROCESSES\n");
	system("pkill gst*");
	system("pkill mjpeg*");
}

void pipecontrol_setup(bool gordon){
	
	//let this priority get inherited to the children
	setpriority(PRIO_PROCESS, getpid(), -10);

	system("sudo -E xinit ~/portal/gstvideo/auto.sh &");
	sleep(5);
	
	system("LD_LIBRARY_PATH=/usr/local/lib mjpg_streamer -i 'input_file.so -f /var/www/html/tmp -n snapshot.jpg' -o 'output_http.so -w /usr/local/www' &");
	
	//kick the core logic up to realtime for faster bit banging
	piHiPri(40);
	
	bash_fp = popen("bash", "w");
	fcntl(fileno(bash_fp), F_SETFL, fcntl(fileno(bash_fp), F_GETFL, 0) | O_NONBLOCK);

	mkfifo ("/home/pi/FIFO_PIPE", 0777 );
	
	if ((web_in = open ("/home/pi/FIFO_PIPE",  ( O_RDONLY | O_NONBLOCK))) < 0) {
		perror("WEB_IN: Could not open named pipe for reading.");
		exit(-1);
	}
	
	fprintf(bash_fp, "sudo chown www-data /home/pi/FIFO_PIPE\n");
	fflush(bash_fp);
	
	if ((temp_in = open ("/sys/class/thermal/thermal_zone0/temp",  ( O_RDONLY | O_NONBLOCK))) < 0) {
		perror("Could not open /sys/class/thermal/thermal_zone0/temp for reading.");
		exit(-1);
	}
	
	if (gordon)	ping_fp = popen("ping -i 0.2 192.168.3.21", "r");
	else		ping_fp = popen("ping -i 0.2 192.168.3.20", "r");

	fcntl(fileno(ping_fp), F_SETFL, fcntl(fileno(ping_fp), F_GETFL, 0) | O_NONBLOCK);	
	
	ifstat_wlan0_fp = popen("ifstat -i wlan0", "r");
	fcntl(fileno(ifstat_wlan0_fp), F_SETFL, fcntl(fileno(ping_fp), F_GETFL, 0) | O_NONBLOCK);
	
	ifstat_bnep0_fp = popen("ifstat -i bnep0", "r");
	fcntl(fileno(ifstat_bnep0_fp), F_SETFL, fcntl(fileno(ping_fp), F_GETFL, 0) | O_NONBLOCK);
	
	iw_fp = popen("bash -c 'while true; do  iw dev wlan0 station dump; echo 'a'; sleep 1; done'", "r");
	fcntl(fileno(iw_fp), F_SETFL, fcntl(fileno(ping_fp), F_GETFL, 0) | O_NONBLOCK);
	
	//empty named pipe
	char buffer[100]; 
	while(read(web_in, buffer, sizeof(buffer)-1));
	
	bcm2835_gpio_fsel(PIN_FAN_PWM, BCM2835_GPIO_FSEL_ALT0); //PWM_CHANNEL 0
	bcm2835_gpio_fsel(PIN_IR_PWM, BCM2835_GPIO_FSEL_ALT0);  //PWM_CHANNEL 1
	
	bcm2835_pwm_set_clock(BCM2835_PWM_CLOCK_DIVIDER_16);
	
	bcm2835_pwm_set_mode(FAN_PWM_CHANNEL, 1, 1); //PWM_CHANNEL 0
	bcm2835_pwm_set_range(FAN_PWM_CHANNEL, 1024);//PWM_CHANNEL 0 Set Range to 1024
	
	bcm2835_pwm_set_mode(IR_PWM_CHANNEL, 1, 1);  //PWM_CHANNEL 1
	bcm2835_pwm_set_range(IR_PWM_CHANNEL, 1024);   //PWM_CHANNEL 1 Set Range to 1024
	
	bcm2835_gpio_fsel(PIN_PRIMARY, BCM2835_GPIO_FSEL_INPT);
	bcm2835_gpio_fsel(PIN_ALT, BCM2835_GPIO_FSEL_INPT);
	bcm2835_gpio_fsel(PIN_MODE, BCM2835_GPIO_FSEL_INPT);
	bcm2835_gpio_fsel(PIN_RESET, BCM2835_GPIO_FSEL_INPT);
	
	bcm2835_gpio_set_pud(PIN_PRIMARY, BCM2835_GPIO_PUD_UP);
	bcm2835_gpio_set_pud(PIN_ALT, BCM2835_GPIO_PUD_UP);
	bcm2835_gpio_set_pud(PIN_MODE, BCM2835_GPIO_PUD_UP);
	bcm2835_gpio_set_pud(PIN_RESET, BCM2835_GPIO_PUD_UP);
}	

void aplay(const char *filename){
	//use dmix for alsa so sounds can play over each other
	fprintf(bash_fp, "aplay -D plug:dmix %s &\n",filename);
	fflush(bash_fp);
}

void web_output(const struct gun_struct *this_gun ){
	static uint8_t web_packet_counter = 0;
	
	FILE *webout_fp;
	
	//send full playlist for editing
	webout_fp = fopen("/var/www/html/tmp/temp.txt", "w");
	fprintf(webout_fp, "%d %d %d %d %d %d %d %d %d %d %d %d %d %d %d %d %d %d %d %d %d %d %d %d %d %d %.2f %.2f %.2f %.2f %d %d\n" ,\
	this_gun->state_solo,this_gun->state_duo,this_gun->connected,this_gun->ir_pwm,\
	this_gun->playlist_solo[0],this_gun->playlist_solo[1],this_gun->playlist_solo[2],this_gun->playlist_solo[3],\
	this_gun->playlist_solo[4],this_gun->playlist_solo[5],this_gun->playlist_solo[6],this_gun->playlist_solo[7],\
	this_gun->playlist_solo[8],this_gun->playlist_solo[9],this_gun->effect_solo,\
	this_gun->playlist_duo[0],this_gun->playlist_duo[1],this_gun->playlist_duo[2],this_gun->playlist_duo[3],\
	this_gun->playlist_duo[4],this_gun->playlist_duo[5],this_gun->playlist_duo[6],this_gun->playlist_duo[7],\
	this_gun->playlist_duo[8],this_gun->playlist_duo[9],this_gun->effect_duo,\
	this_gun->battery_level_pretty,this_gun->temperature_pretty,this_gun->coretemp,\
	this_gun->latency,web_packet_counter,this_gun->mode);
	fclose(webout_fp);
	rename("/var/www/html/tmp/temp.txt","/var/www/html/tmp/portal.txt");
	
	web_packet_counter++;
}

int read_web_pipe(struct gun_struct *this_gun){
	int web_button = BUTTON_NONE;
	int count = 1;
	char buffer[100];
	//stdin is line buffered so we can cheat a little bit
	while (count > 0){ // dump entire buffer
		count = read(web_in, buffer, sizeof(buffer)-1);
		if (count > 1){ //ignore blank lines
			buffer[count-1] = '\0';
			//keep most recent line
			int tv[11];
			printf("MAIN Web Command: '%s'\n",buffer);
			int results = sscanf(buffer,"%d %d %d %d %d %d %d %d %d %d %d", &tv[0],&tv[1],&tv[2],&tv[3],&tv[4],&tv[5],&tv[6],&tv[7],&tv[8],&tv[9],&tv[10]);
			//button stuff
			if (tv[0] == 1 && results == 2) {
				switch (tv[1]){
				case WEB_PRIMARY_FIRE:	web_button = BUTTON_PRIMARY_FIRE;  	break;
				case WEB_ALT_FIRE:		web_button = BUTTON_ALT_FIRE;    	break;
				case WEB_MODE_TOGGLE:	web_button = BUTTON_MODE_TOGGLE; 	break; 
				case WEB_RESET:     	web_button = BUTTON_RESET; 			break; 
				default: 				web_button = BUTTON_NONE;
				}
			}
			
			//pad out array with repeat (-1) once encountered
			if (results == 11){
				uint8_t filler = 0;
				for (uint8_t i = 1; i < 11; i++){
					if (tv[i] == -1) filler = -1;
					if (filler == -1) tv[i] = -1;
				}
			}
			
			//ir stuff
			if (tv[0] == 2 && results == 2) {
				if (tv[1] >= 0 && tv[1] <= 1024) this_gun->ir_pwm = tv[1];
			}
			//self playlist setting
			else if (tv[0] == 3 && results == 11) {
				for (uint8_t i = 0; i < 10; i++){
					this_gun->playlist_solo[i] = tv[i+1];
				}
			}
			//shared playlist setting
			else if (tv[0] == 4 && results == 11) {
				for (uint8_t i = 0; i < 10; i++){
					this_gun->playlist_duo[i] = tv[i+1];
				}
			}
			
		}
	}
	return web_button;
}

void update_ping(float * ping){
	static uint32_t ping_time = 0;
	int count = 1;
	char buffer[100];
	//stdin is line buffered so we can cheat a little bit
	while (count > 0){ // dump entire buffer
		count = read(fileno(ping_fp), buffer, sizeof(buffer)-1);
		if (count > 1){ //ignore blank lines
			buffer[count-1] = '\0';
			int placemarker = 0;
			int equals_pos = 0;
			while (placemarker < count-2){
				if (buffer[placemarker] == '=') equals_pos++;
				placemarker++;
				if (equals_pos == 3){
					sscanf(&buffer[placemarker],"%f", ping);
					ping_time = millis();
					break;
				}
			}
		}
	}
	if (millis() - ping_time > 1000) *ping = 0.0;
}
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

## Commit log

2020-01-07 rm led test
2020-01-13 Plugins
    Fix rpicamsrc, libvisual, and start capturing wlan0 stats
    [pipecontrol.cpp, portal.cpp]
2020-01-16 cleanup
    fix reading pipes and tune visualization
    [pipecontrol.cpp]
2020-02-03 portal spin
    basic portal spin (wrong direction)
    [memory.c, pipe.c, portal.c]
2020-02-06 render timer
2020-02-09 shimmer shader
    remove all textures, switch to only shaders
2020-02-20 gyro init
    starting gyro
2020-02-21 particle offset
    switch calculating particle offset from looping over destination to looping over source for cleaner implementation
2020-02-23 logging & gyro
    move gyro code into main where it runs at the same fixed rate as the sensor & clean up logging
    [drm-common.c, i2c.c, memory.c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]
2020-03-04 Update bcm2835 & sound driver
2020-03-11 fix hostapd
    hack fix for hostapd and pwm fighting
    [portal.c]
2020-03-11 25khz pwm
    Switch to 25khz PWM and alter bcm commands as workaround for pwm-2chan overlay
    [config.txt]
2020-03-12 remove sound driver
    now included in linux kernel 4.19.106
2020-03-16 servo bypass logic
    servo bypass logic
2020-03-16 double tap reset
    double tap reset to force shutdown laser immediately
    [pipe.c, state.c]
2020-03-17 Update projector_logic.c
    fix jackdaw and oinksie corruption since they apparently do not stop emitting frames if paused. previously we had to pause alsasrc to prevent long init times, but in buster nulling is apparently fine.
2020-03-18 corona, video & lan
    Add corona effect, fix video playback handling, and update intranet to remove live video which hasnt existed since v2
    [effects.h]
2020-03-18 add effects
    add effects, and switch to audio loopback
2020-04-14 current meter
    initial current
2020-05-07 Shutter & Camera
    Fix Fancy Shutter & Enable Laser Warmup in Duo Camera
    [state.c]
2020-05-10 fix race condition
    fix a state machine race condition, update leds to match portal gun v4 state machine
    [led.c, state.c]
2020-05-10 long press reboot
    reboot on long reset press, show countdown on console
    [io.c, io.h, portal.c]
2020-06-01 bump bcm2835
    bump bcm2835, update logo, usb bt
    [3D.dwg, config.txt]
2020-06-01 speed up boot
    speed up bootup by 10 seconds
    [config.txt]
2020-06-04 factor out i2c drivers & initial sgtl5000 driver
    factor out i2c drivers and initial sgtl5000 driver
2020-06-08 video fixes
    fix video playback, add specific asoundrc, fix solo blue state 1 sound, switch to singular videos, fix synae init via preloading wave
    [effects.h, pipe.c, state.c]
2020-06-11 change dir layout
    [3D.dwg, Sheets.dwg, config.txt]
2021-08-07 New HW
    Start of the new HW for 4.1, new LEDs, new IMU, fix audio driver not selecting
    [LSM6.c, i2c.c, led.c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]
2021-08-10 Button Pins
    Update remote pins and enable remote button
2021-09-06 Remote button fix
2021-09-26 Update pipe.c
    fix typo
    [pipe.c]
2021-09-27 fix remote button
2021-09-28 Update stats
    iw no longer outputs signal quality when using hostapd, change to show rx over tx. also disable hdmi audio, and update notes on image used.
    [pipe.c]
2021-10-19 add pcb
    add pcb
2021-10-31 finger tips
    [finger andle.stl, finger arm.SLDPRT, finger arm.STL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]
2021-11-02 trim cad
    [front trim holes only.stl]
2022-01-22 initial bullseye
    [config.txt]
2022-01-26 fix projector pipelines
    workable pipelines for all solo effects, fixed dmesg error
    [pipe.c, portal.c]
2022-02-02 double init drm fix
    hacky but works reliably
    [pipe.c]
2022-02-02 kms init fix
    I don't know what isn't being init during boot, but this delay reliably fixes all problems.
    [pipe.c]
2022-02-03 update configs
    [config.txt]
2022-02-26 Front Update
    Add holes for webbing.
    [front holes.SLDPRT, front holes.STL]
2023-04-14 Battery Level Warning
2023-07-12 fkms to kms and vcgencmd to dpms
    [config.txt]
2023-07-13 leds - bcm2835 to spidev
    slightly slower if I just measure the call, but not enough to show up in the overall cpu time consumed
2023-07-13 i2c bcm2835 to i2cdev
2023-07-15 Bullseye 64-bit
    [config.txt]
